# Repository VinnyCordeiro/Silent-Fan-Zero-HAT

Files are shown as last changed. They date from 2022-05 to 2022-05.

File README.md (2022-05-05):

# Silent Fan Zero HAT
## A PWM to DC voltage conversion in HAT form factor

This board is based on the work of Róbert Lőrincz, from Transylvania, Romania (yes, from the place of Dracula). You can see the original board [here](https://orbiterprojects.com/silent-fan-driver/).

The main purpose of this board is to transform a PWM signal into a DC voltage, with benefits being:
* Lower fan noise;
* Better speed control;
* Longer fan lifetime;
* Lower fan vibrations.

Also, you (theoretically) can control lower voltage fans with this board by setting the maximum fan speed to lower values: using a 24V power supply, you'd use a maximum fan speed of 50% for a 12V fan, and 20% for a 5V fan.

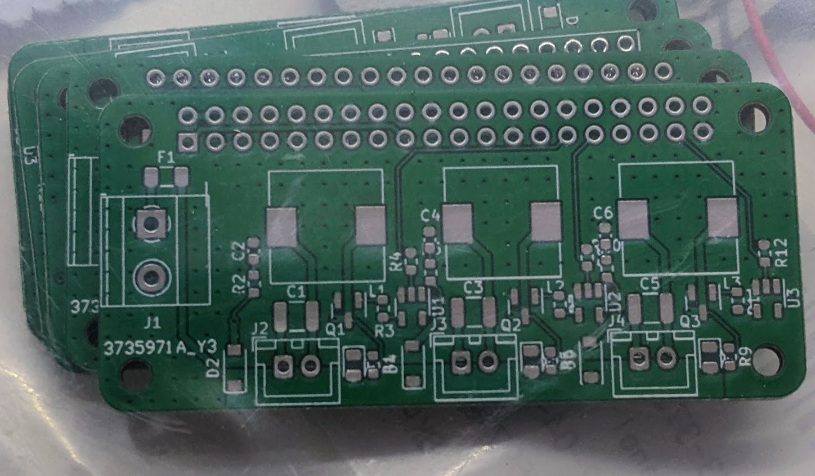
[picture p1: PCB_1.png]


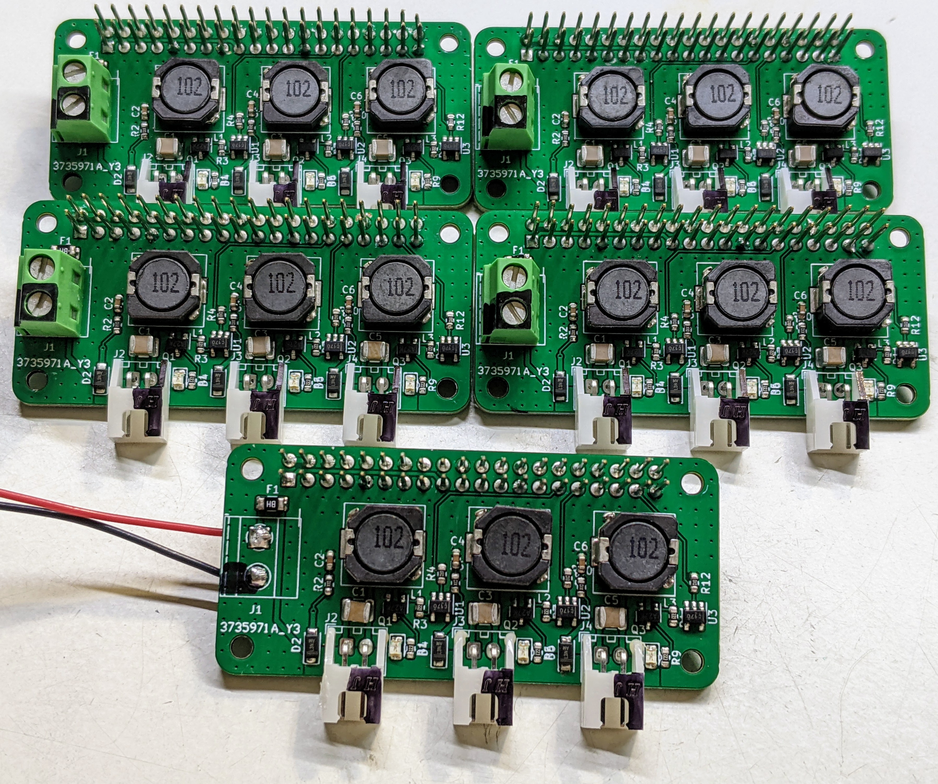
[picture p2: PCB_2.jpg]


(Photos courtesy of Infinite Entropy, from Voron Discord server)

### UPDATES:

May 4th, 2022: Initial public release (on Star Wars Day! May the Fourth be with you!). I had to reupload many files due to the fact that the pre-release version had messed up silkscreen. 🙃

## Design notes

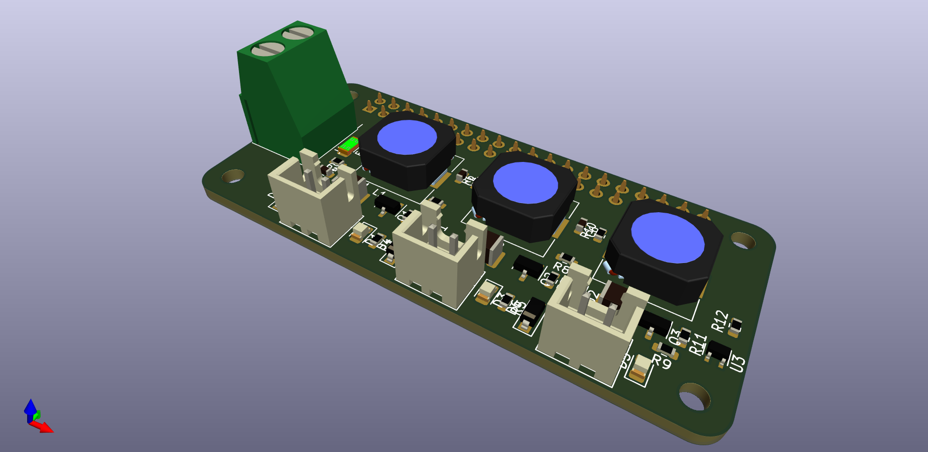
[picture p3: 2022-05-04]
SilentFanZeroHAT.png

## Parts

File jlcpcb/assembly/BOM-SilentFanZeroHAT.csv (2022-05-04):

Comment | Designator | Footprint | LCSC
Fan_0 | J2,J3,J4 | JST_XH_B2B-XH-A_1x02_P2.50mm_Vertical | C158012
74LVC1G17 | U1,U2,U3 | SOT-23-5 | C202202
10R | R10,R2,R6 | R_0603_1608Metric | C22859
220R | R11,R3,R7 | R_0603_1608Metric | C22962
100k | R12,R4,R8 | R_0603_1608Metric | C25803
22k | R1,R5,R9 | R_0603_1608Metric | C31850
Conn_02x20_Odd_Even | P1 | PinSocket_2x20_P2.54mm_Vertical | C35165
10µF | C1,C3,C5 | C_1210_3225Metric | C39232
1mH | L1,L2,L3 | L_10.4x10.4_H4.8 | C397811
PMEG3020EGWX | D2,D4,D6 | D_SOD-123 | C475720
AOSS32338C | Q1,Q2,Q3 | SOT-23 | C489373
10nF | C2,C4,C6 | C_0603_1608Metric | C57112
RED | D1,D3,D5 | LED_0805_2012Metric | C84256
~ | F1 | Fuse_1206_3216Metric | C910830
24V Input | J1 | TerminalBlock_Phoenix_MKDS-1,5-2-5.08_1x02_P5.08mm_Horizontal | C91153
M2.5 | MK1 | MountingHole_2.7mm_M2.5
M2.5 | MK3 | MountingHole_2.7mm_M2.5
M2.5 | MK2 | MountingHole_2.7mm_M2.5
M2.5 | MK4 | MountingHole_2.7mm_M2.5

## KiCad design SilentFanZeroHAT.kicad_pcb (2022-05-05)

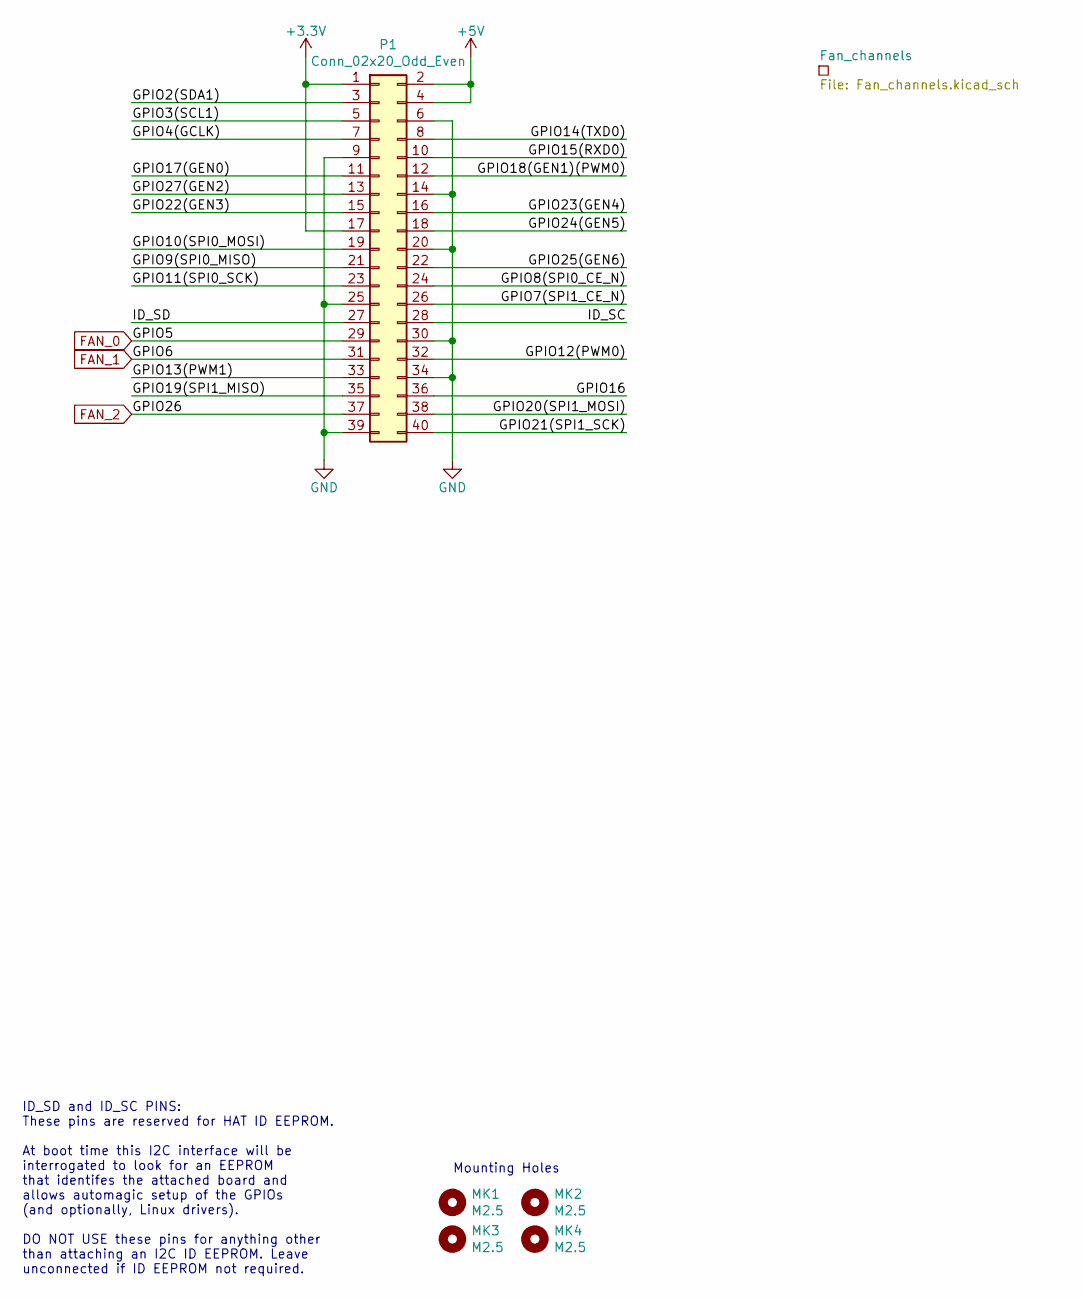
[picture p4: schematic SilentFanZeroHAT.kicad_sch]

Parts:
MK1, MK2, MK3, MK4: M2.5; MountingHole_2.7mm_M2.5
P1: Conn_02x20_Odd_Even; PinSocket_2x20_P2.54mm_Vertical

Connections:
+3V3: P1.1, P1.17
+5V: P1.2, P1.4; also elsewhere on the board
/GPIO2(SDA1): P1.3
/GPIO3(SCL1): P1.5
/GPIO4(GCLK): P1.7
/GPIO7(SPI1_CE_N): P1.26
/GPIO8(SPI0_CE_N): P1.24
/GPIO9(SPI0_MISO): P1.21
/GPIO10(SPI0_MOSI): P1.19
/GPIO11(SPI0_SCK): P1.23
/GPIO12(PWM0): P1.32
/GPIO13(PWM1): P1.33
/GPIO14(TXD0): P1.8
/GPIO15(RXD0): P1.10
/GPIO16: P1.36
/GPIO17(GEN0): P1.11
/GPIO18(GEN1)(PWM0): P1.12
/GPIO19(SPI1_MISO): P1.35
/GPIO20(SPI1_MOSI): P1.38
/GPIO21(SPI1_SCK): P1.40
/GPIO22(GEN3): P1.15
/GPIO23(GEN4): P1.16
/GPIO24(GEN5): P1.18
/GPIO25(GEN6): P1.22
/GPIO27(GEN2): P1.13
/ID_SC: P1.28
/ID_SD: P1.27
FAN_0: P1.29; also elsewhere on the board
FAN_1: P1.31; also elsewhere on the board
FAN_2: P1.37; also elsewhere on the board
GND: P1.6, P1.9, P1.14, P1.20, P1.25, P1.30, P1.34, P1.39; also elsewhere on the board

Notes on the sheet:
ID_SD and ID_SC PINS: These pins are reserved for HAT ID EEPROM. At boot time this I2C interface will be interrogated to look for an EEPROM that identifes the attached board and allows automagic setup of the GPIOs (and optionally, Linux drivers). DO NOT USE these pins for anything other than attach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
Mounting Holes

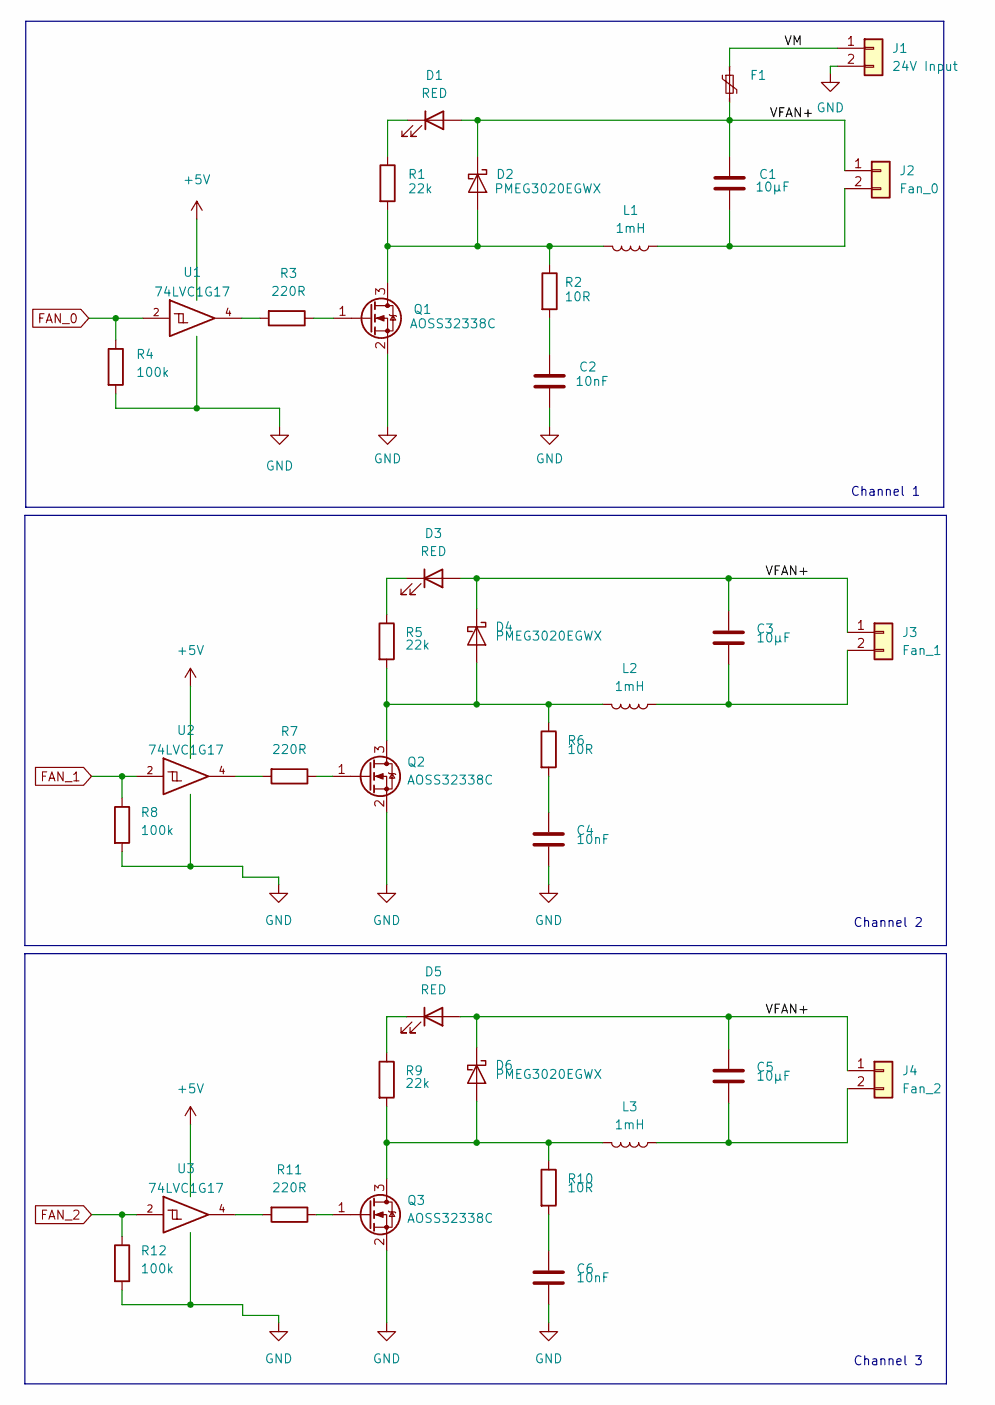
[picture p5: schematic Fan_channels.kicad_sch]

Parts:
C1, C3, C5: 10µF; C_1210_3225Metric
C2, C4, C6: 10nF; C_0603_1608Metric
D1, D3, D5: RED; LED_0805_2012Metric
D2, D4, D6: PMEG3020EGWX; D_SOD-123
F1: Fuse_1206_3216Metric
J1: 24V Input; TerminalBlock_Phoenix_MKDS-1,5-2-5.08_1x02_P5.08mm_Horizont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; JLCPCB C91153
J2: Fan_0; JST_XH_B2B-XH-A_1x02_P2.50mm_Vertical
J3: Fan_1; JST_XH_B2B-XH-A_1x02_P2.50mm_Vertical
J4: Fan_2; JST_XH_B2B-XH-A_1x02_P2.50mm_Vertical
L1, L2, L3: 1mH; L_10.4x10.4_H4.8
Q1, Q2, Q3: AOSS32338C; SOT-23
R1, R5, R9: 22k; R_0603_1608Metric
R2, R6, R10: 10R; R_0603_1608Metric
R3, R7, R11: 220R; R_0603_1608Metric
R4, R8, R12: 100k; R_0603_1608Metric
U1, U2, U3: 74LVC1G17; JLCPCB C10425

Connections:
+5V: U1.5 (VCC), U2.5 (VCC), U3.5 (VCC); also elsewhere on the board
/Fan_channels/VFAN+: C1.1, C3.1, C5.1, D1.2 (A), D2.1 (K), D3.2 (A), D4.1 (K), D5.2 (A), D6.1 (K), F1.2, J2.1, J3.1, J4.1
/Fan_channels/VM: F1.1, J1.1
FAN_0: R4.1, U1.2; also elsewhere on the board
FAN_1: R8.1, U2.2; also elsewhere on the board
FAN_2: R12.1, U3.2; also elsewhere on the board
GND: C2.2, C4.2, C6.2, J1.2, Q1.2 (S), Q2.2 (S), Q3.2 (S), R4.2, R8.2, R12.2, U1.3 (GND), U2.3 (GND), U3.3 (GND); also elsewhere on the board
unnamed: C1.2, J2.2, L1.1
unnamed: C2.1, R2.2
unnamed: C3.2, J3.2, L2.1
unnamed: C4.1, R6.2
unnamed: C5.2, J4.2, L3.1
unnamed: C6.1, R10.2
unnamed: D1.1 (K), R1.1
unnamed: D2.2 (A), L1.2, Q1.3 (D), R1.2, R2.1
unnamed: D3.1 (K), R5.1
unnamed: D4.2 (A), L2.2, Q2.3 (D), R5.2, R6.1
unnamed: D5.1 (K), R9.1
unnamed: D6.2 (A), L3.2, Q3.3 (D), R9.2, R10.1
unnamed: Q1.1 (G), R3.1
unnamed: Q2.1 (G), R7.1
unnamed: Q3.1 (G), R11.1
unnamed: R3.2, U1.4
unnamed: R7.2, U2.4
unnamed: R11.2, U3.4

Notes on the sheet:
Channel 2
Channel 1
Channel 3

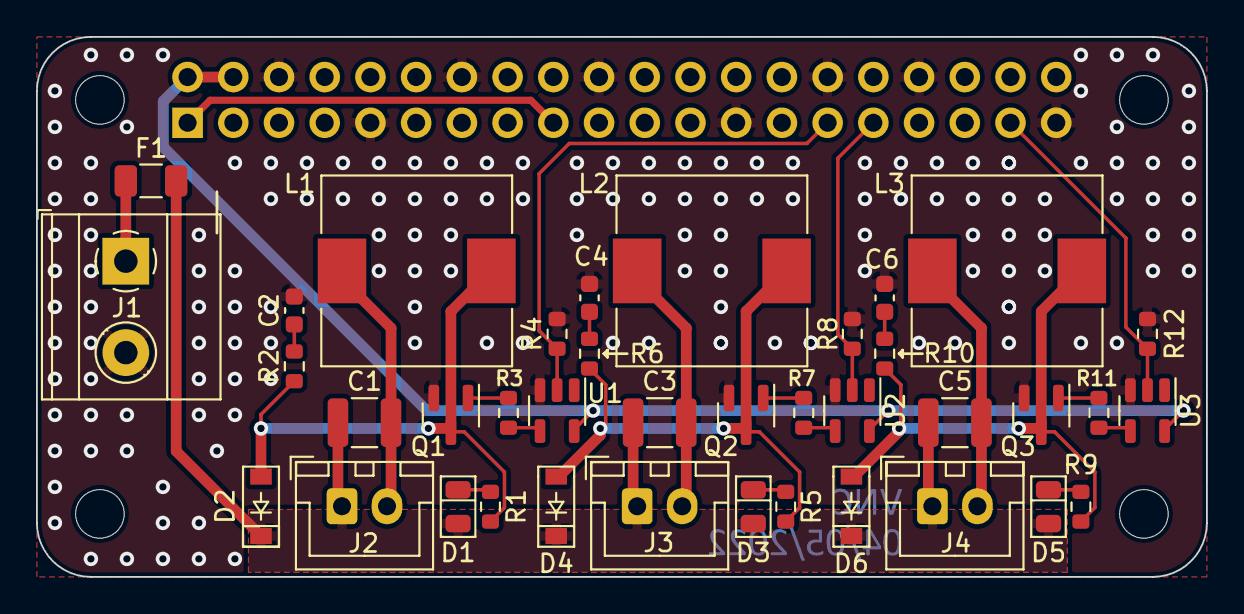
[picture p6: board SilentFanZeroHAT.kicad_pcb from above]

Board: 2 copper layers, 65.0 x 30.0 mm, 43 parts (1 on the bottom side), 26 nets.

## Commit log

2022-05-04 Initial upload
    [BOM-SilentFanZeroHAT.csv, Fan_channels.kicad_sch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]
2022-05-05 Fixing the silkscreen mess
    Thanks Infinite Entropy for alerting me about that.
    [SilentFanZeroHAT-CuBottom.gbr, SilentFanZeroHAT-CuTop.gbr, SilentFanZeroHAT-EdgeCuts.gbr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]
